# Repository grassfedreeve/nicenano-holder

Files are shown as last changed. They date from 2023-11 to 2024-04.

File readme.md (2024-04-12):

## Holder PCB for nice!nano

### nice!nano v2 holder PCB for Bastard Keyboards Charybdis
### WARNING: The PCBs have been printed and tested, however not an Electrical Engineer use at your own risk and go over the files before ordering any prototypes.

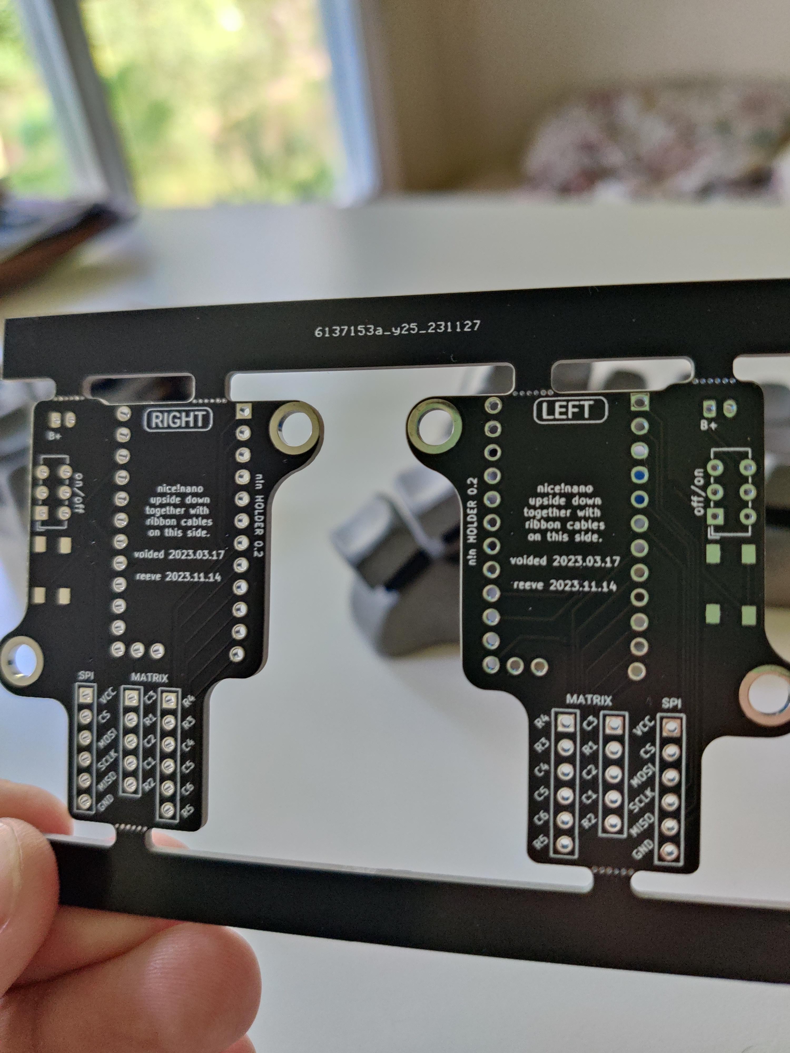
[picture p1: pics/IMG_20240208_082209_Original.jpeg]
nice!nano v2 holder


### Features:
- matrix pinout moved to low frequency pins
- spi trackball connection moved to high frequency pins
- removed rgb and serial connection
- repositioned reset footprint
- replaced and repositioned on/off
- ph2 battery connector

## BOM

Power Switch: https://au.mouser.com/ProductDetail/CK/JS202011CQN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

Reset Button: Button, 4x4x1.5 https://www.aliexpress.com/item/1005001304569553.html?spm=a2g0s.9042311.0.0.27424c4dDwgcp7

Ultra Low Profile Sockets: 315-43-164-41-003000
Other sockets will not be low enough to fit USBC cutout.

# License 

This work is licensed under a Creative Commons Attribution-NonCommercial-ShareAlike 4.0 International License.

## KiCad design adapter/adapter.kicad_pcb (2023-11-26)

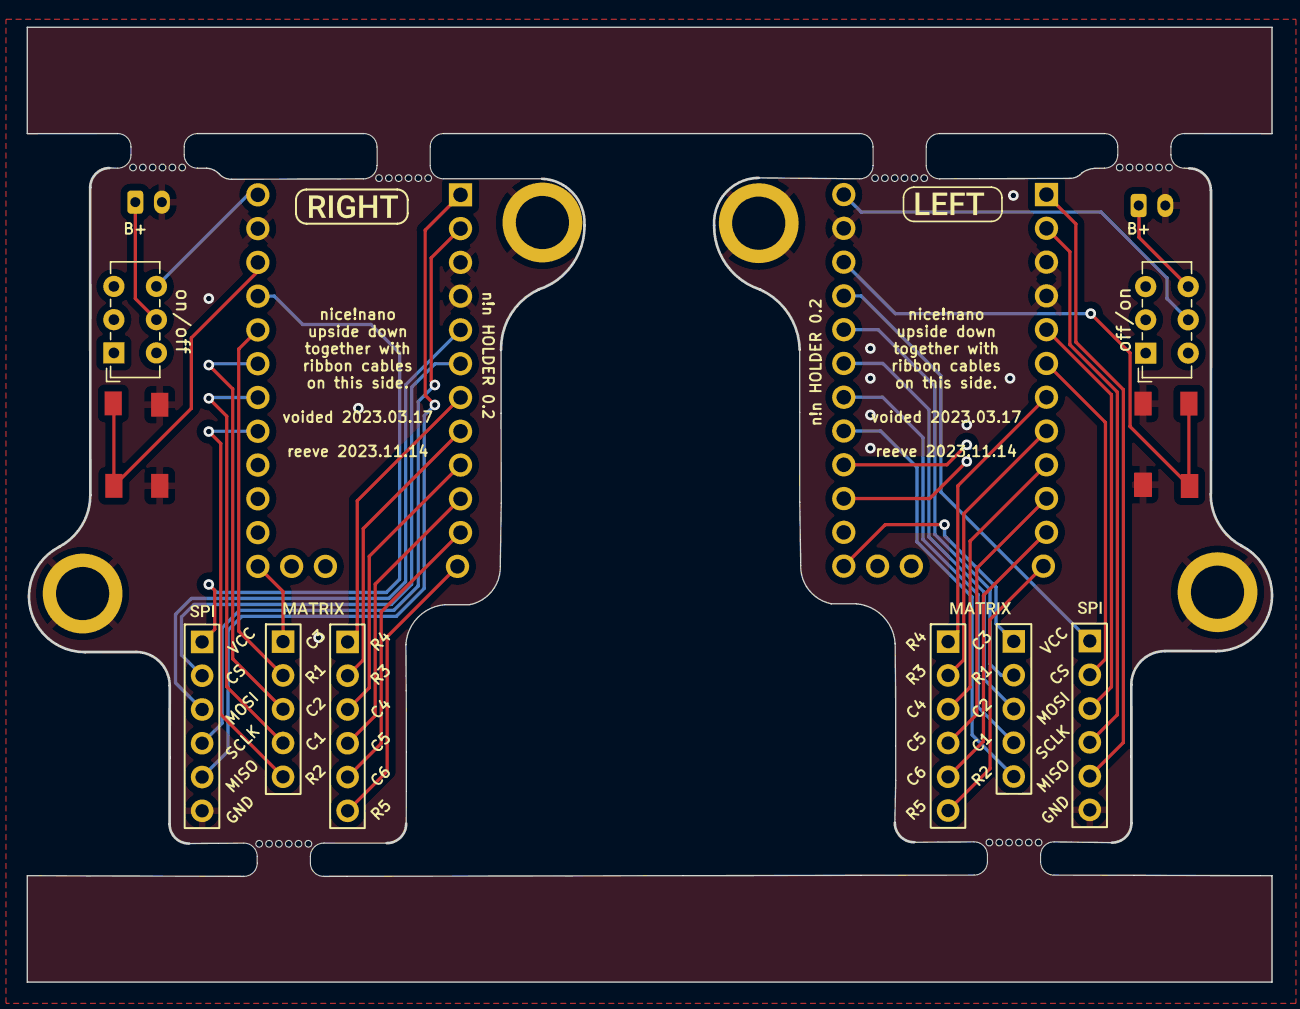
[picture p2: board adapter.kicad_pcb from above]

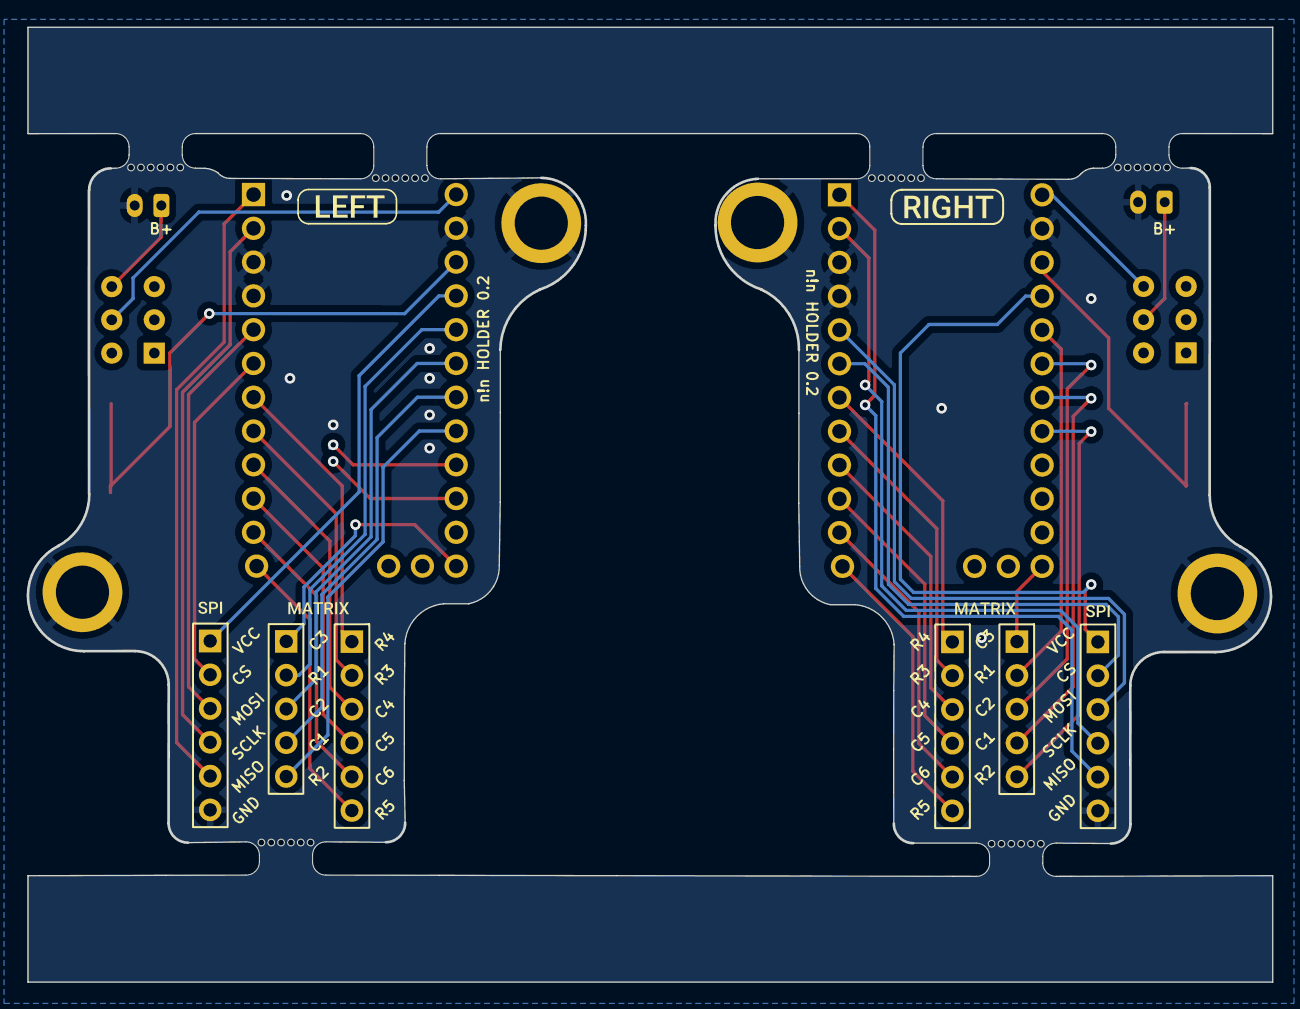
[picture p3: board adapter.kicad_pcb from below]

Board: 2 copper layers, 93.6 x 71.8 mm, 29 parts (8 on the bottom side), 36 nets.

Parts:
H1, H2, H3, H4: M4; MountingHole_4mm_Pad_thin
J3, J6: battery charge; JST_PH_B2B-PH-K_1x02_P2.00mm_Vertical
J7, J8: trackball; 6_PinHeader
J9, J11: Ribbon; 5_PinHeader
J10, J12: Ribbon; 6_PinHeader
SW1, SW2: SW_SPST; PushSwitch
U1, U2: eliteC; Elite-C
kibuzzard-61F01B61, kibuzzard-61F01B61#2: G***; kibuzzard-61F01B61
kibuzzard-61F01940, kibuzzard-61F01940#2, kibuzzard-61F01940#3, kibuzzard-61F01940#4: G***; kibuzzard-61F01940
kibuzzard-61F01957, kibuzzard-61F01957#2, kibuzzard-61F01957#3, kibuzzard-61F01957#4: G***; kibuzzard-61F01957
kibuzzard-6208EFFE, kibuzzard-6208EFFE#2: G***; kibuzzard-6208EFFE
off/on: SW_E-Switch_EG1271_SPDT

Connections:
+5V: J7.1, J8.1, U1.21 (VCC), U2.21 (VCC)
GND: H1.1, H2.1, H3.1, H4.1, J3.2, J6.2, J7.6, J8.6, SW1.2 (B), SW2.2 (B), U1.3 (GND), U1.4 (GND), U1.23 (GND), U2.3 (GND), U2.4 (GND), U2.23 (GND)
Rst: SW1.1 (A), U1.22 (RST)
Rst2: SW2.1 (A), U2.22 (RST)
bat_r: U2.24 (RAW), off/on.5
bat_sw_r: J6.1, off/on.6
col1_l: J9.4, U1.18 (F6)
col1_r: J11.4, U2.18 (F6)
col2_l: J9.3, U1.19 (F5)
col2_r: J11.3, U2.19 (F5)
col3_l: J9.1, U1.13 (B6)
col3_r: J11.1, U2.13 (B6)
col4_l: J10.3, U1.9 (D7)
col4_r: J12.3, U2.9 (D7)
col5_l: J10.4, U1.10 (E6)
col5_r: J12.4, U2.10 (E6)
col6_l: J10.5, U1.11 (B4)
col6_r: J12.5, U2.11 (B4)
miso_l: J7.5, U1.1 (TX)
miso_r: J8.5, U2.1 (TX)
mosi_l: J7.3, U1.5 (SCL)
mosi_r: J8.3, U2.5 (SCL)
row1_l: J9.2, U1.20 (F4)
row1_r: J11.2, U2.20 (F4)
row2_l: J9.5, U1.17 (F7)
row2_r: J11.5, U2.17 (F7)
row3_l: J10.2, U1.8 (C6)
row3_r: J12.2, U2.8 (C6)
row4_l: J10.1, U1.7 (D4)
row4_r: J12.1, U2.7 (D4)
row5_l: J10.6, U1.12 (B5)
row5_r: J12.6, U2.12 (B5)
sc_l: J7.4, U1.2 (RX)
sc_r: J8.4, U2.2 (RX)
ss_l: J7.2, U1.6 (SDA)
ss_r: J8.2, U2.6 (SDA)

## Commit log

2023-11-17 v0.2
    removed serial ports
    moved reset to be reachable
    replace on/off switch to top and swapped to vertical through hole
    [adapter.kicad_pcb, adapter.kicad_sch]
2023-11-26 Small fixes
    [adapter.kicad_pcb]
2023-11-26 Updated Gerber

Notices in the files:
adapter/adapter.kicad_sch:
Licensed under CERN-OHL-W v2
